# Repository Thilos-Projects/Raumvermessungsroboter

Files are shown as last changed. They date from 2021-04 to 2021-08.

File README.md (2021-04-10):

__Das Projekt findet in Coop mit [Tom Seiffert](https://github.com/Tomsei "Tom Seiffert") statt.__

# Raumvermessungsroboter
## Ziel:

Ein möglichst *einfacher* und *kleiner* Roboter der *autonom* einen flachen Raum von ca. 20x20m abfahren kann und den abgefahrenen Bereich auf einer einfachen Website darstellt.

Hierbei sollen Hindernissen ausgewichen und Kanten vermieden werden.
Nach Möglichkeit sollen nicht statische Hindernisse erkannt und in der Ansicht aktualisiert werden.

Im Weiteren soll der Roboter *keine* äußeren Stationen oder Rechenkapazitäten benötigen. Eine Fernsteuerung für manuelle Operationen soll über ein web interface ermöglicht werden.
Die Entfernungsmessung soll OnBoard über ein *eigenbau* LiDAR System geschehen.
 
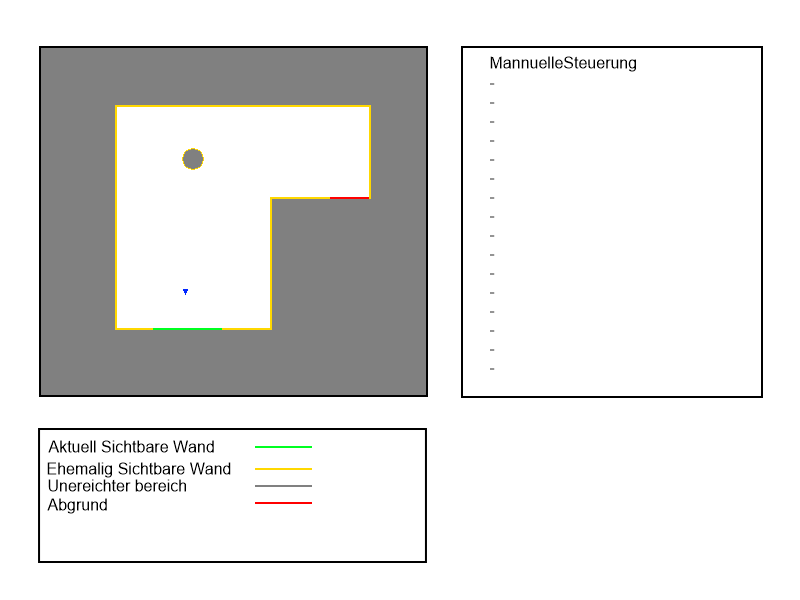
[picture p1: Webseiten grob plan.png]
Webseiten Bild
 
 
## Optionale Erweiterungen:

* Der Roboter soll es ermöglichen ihn an einen punkt in dem gescannten Bereich zu schicken.
* Die daten der Raumvermessung sollen für einen externen Computer über eine schnittstalle in Echtzeit lesbar sein.
* Der Roboter priorisiert in der Raumvermessung Bereiche nah einem gegebenen Punkt über Bereiche, die weiter von diesem entfernt sind.
* Die Webseite zeigt geplante Bewegungen grafisch an.

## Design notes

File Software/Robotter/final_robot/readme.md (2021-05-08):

# Setupinformationen:

* **Entwicklungsboard:** DOIT ESP32 DEVKIT V1

* **Core Debug Level:** None

* **Flash Frequenzy:** 80 Mhz

* **Upload Speed:** 921600

* **Serial Monitor:** 115200

# Code Architektur:

* **Header Programm:** es werden keine .cpp verwendet, sondern nur .h

* **Interrupts:** Management Über Eventssystem

* **Libraries:** Manuell eingebunden im libs Ordner. Gemeinsamer include durch lib_include.h

* **Komponenten:** Komponente wenn möglich als eigenständige Klasse -> Bsp. Motoren, Bodenabstandsmesser...

### Kapselung der Komponenten in Gruppen

1. **Grundkomponenten / Basics:** 
* Motoren 
* Bodenabstandsmesser 
* Ultraschallsensor 
* Laserentfernungsmesser 
* Maussensor 
* Akkustand 
* WiFi 
* LEDs 
* PIN-API
* Lidar-Poty 
* SD Karte 
* Entladeschutz

2. **Komponentenkombiation:** 
* Fahrwerk (1 Seite) -> Motor + Bodenabstandsmesser
* Lidarsystem -> Laserentfernungsmesser + Lidar Poty + Motor
* Abschaltung -> Akuustand + Entladeschutz
* Debughandler -> LEDs + Serielle Schnittstelle

3. **Hauptkomponenten:** 
* Fahrkontrolle --> 2 Fahrwerke + Ultraschallsensor + Maussensor
* Datenkontrolle --> SD Karte
* Lidarkontrolle --> Lidarsystem
* API-Schnittstelle --> WiFi + Pinne 

# Code Style

* Dokumentation auf Deutsch
* Code auf Englisch

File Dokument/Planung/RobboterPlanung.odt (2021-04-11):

Planung

Nötige teile:

- Akku
  - 12V
  - Ladeadapter OnBoard
  - Genug Strom für 20mx20m
- Motoren
  - Schrittmotoren
  - 12V
- Lidar
  - Laser
  - Servos
    - 5V/12V
    - Genauigkeit vor Tempo
- Hinderniserkennung
  - Ultraschallsensor?
- Treppen/Fall Vermeidung
  - Infrarot Reflektion Lichtschranke
- Ketten
  - Glatter wie nicht glatter Untergrund
- LaserMausSensor
  - adns-9800 laser mouse
- Platine
  - Spannungswandler
    - 12V -> 5V
  - Motortreiber/Servotreiber
    - 12V
  - Batterieschutz
    - Lade/Entlade/Kurzschluss/Überspannung
  - Akkuladekreis
  - Ladeanzeige
    - 5 Leds
- Microcontroller
  - Wlan-Host
  - Host für Webseite (Rechenleistung)
- Led
  - Status
    - Ladestand?
  - Designe
  - …
- Knöpfe
  - An/Aus
  - Start/Stopp
  - Ladestand
  - Cash leeren
  - Restart
- Webseite
  - Start/Stopp
- SD-Karte/Speichererweiterung
- Es geht runter Sensor

Motoren: https://www.amazon.de/MVPOWER-Schrittmotor-Stepper-Phase-4-Stepping/dp/B07CZHLKTC/

- 1.5 A | 2.4 V
- 35€ | 5 Motoren | 2 pro Roboter

Motortreiber: https://www.amazon.de/AZDelivery-A4988-Schrittmotor-Treiber-Modul-K%C3%BChlk%C3%B6rper-inklusive/dp/B083V59HTB/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

Datenblatt: https://www.pololu.com/file/0J450/a4988_DMOS_microstepping_driver_with_translator.pdf

- 9€ | 5 Motortreiber | 2 pro Roboter

Servo Motor: Problem keinen richtigen 360° Servo gefunden

- Daher weggeworfen | Eigenbau Poti mit DC Motor

DC Motor: Kreisdrehung https://www.amazon.de/Yosoo-Drehmoment-Getriebemotor-Getriebe-Spielzeug/dp/B01BBSXDJ4/

- 12V | ca.100 ma.
- 6,60€ | 1 Motor | 1 Motor pro Roboter

DC Motortreiber: https://www.amazon.de/Bridge-Driver-Stepper-Controller-Arduino/dp/B077NY9RY6

- 9€ | 2 Treiber | 1 Treiber pro Roboter

Laser Entfernungsmessung: https://www.mouser.de/ProductDetail/Seeed-Studio/101990656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

Datenblatt: https://www.mouser.de/datasheet/2/744/SJ-GU-TF-luna-A01_2bDatasheet-1841241.pdf

- 18€ | ein Abstandsmesser | 1 pro Roboter
- 5V | 3,3V Signal | 70ma

Ultraschallsensoren: https://www.amazon.de/HC-SR04-Ultraschall-Modul-Entfernungssensor-Raspberry-MEGA2560-blau/dp/B081PZF4T3/

- 7€ | 5 Ultraschall | 2 pro Roboter
- 5V

Boden Abstandsmesser | Infrarot Lichtschranke: https://www.amazon.de/MissBirdler-TCRT5000-Lichtschranke-Reflexlichtschranke-Raspberry/dp/B07Q3X9J2V/

- 6 € | 2 im Angebot | 4 pro Roboter -> 12 €

Maus Sensor: https://de.aliexpress.com/item/4000354356293.html?

- 5€ | 1 im kauf | 1 pro Roboter

SD Karten Reader: https://www.amazon.de/AZDelivery-Reader-Speicher-Memory-Arduino/dp/B077MCQS9P/

- 6€ | für 3 | 1 pro Roboter

SD Karte: Laden

Tabelle:

Komponente | Preis | Anzahl | Anzahl im Roboter | Kauf link | Datenblattlink|

Ziele:

- Autonom Fahren
- 20mx20m Fahrbereich
- Webseite Hosting mit raum Darstellungen
- Hindernisse erkennen
- Treppen/Fall Vermeidung
- Hindernisse und fall stellen dynamisch eintragen
- Alles OnBoard
- Fernsteuerung über Web interface
- Entfernung Messung über LiDAR

Optionale Ziele:

- Miniatur tanz Animation
- Manuelle punkt Positionierung
- Webseite mit Rohdaten in Echtzeit
- Scann Logik mit punkt Priorisierung
- Geplante/Alte Bewegungen darstellen (Webseite/Leds)

Meilensteine:

1. Roboter ist fertig
  a. Hardware ist fertig
    i. Spannungsversorgung
      1. Batterie Strom
      2. 5V Leitung
      3. Ladevorgang
      4. Schutzelektronik
    ii. Platine
      5. Alle Teile sind geplant/vorhanden
        a. Einzelkomponenten funktionieren
      6. Platine ist geplant und getestet
    iii. LiDAR
      7. Sensor vorhanden/funktionsfähig
      8. Servos funktionsfähig
      9. 3D Modell für Halterung fertig/gedruckt und passend
    iv. Eventuelle 3D Komponenten
      10. Komponenten/ Halterungen modelliert
      11. Komponenten/ Halterungen gedruckt und passend
    v. Roboter Zusammenbau
  b. Software ist fertig
    vi. Komponenten Test
      12. Platine
        b. Einzel Komponenten Tests
        c. Gruppen Komponenten Tests
        d. Einfache Fahrroutiene
      13. LiDAR
        e. Laser liefert Abstandes werte
        f. Servo dreht richtig
        g. Daten sind ab speicherbar
      14. Webseite
        h. Daten in Tabelle
        i. Daten darstellen (Skizze)
        j. Manuelle Steuerung
          i. Joystick
          ii. Fahr zu punkt
        k. Schön machen
    vii. Gruppen Test
      15. Einfache Fahrroutiene plus scannen und darstellen
      16. Punkt anfahren
      17. Ruhe Task (Leds?)

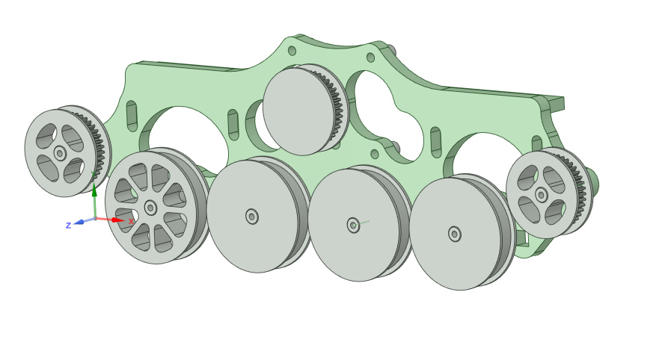
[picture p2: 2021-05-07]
Dokument/Bilder/Fahrwerk/Fahrwerk_Planung_1.PNG

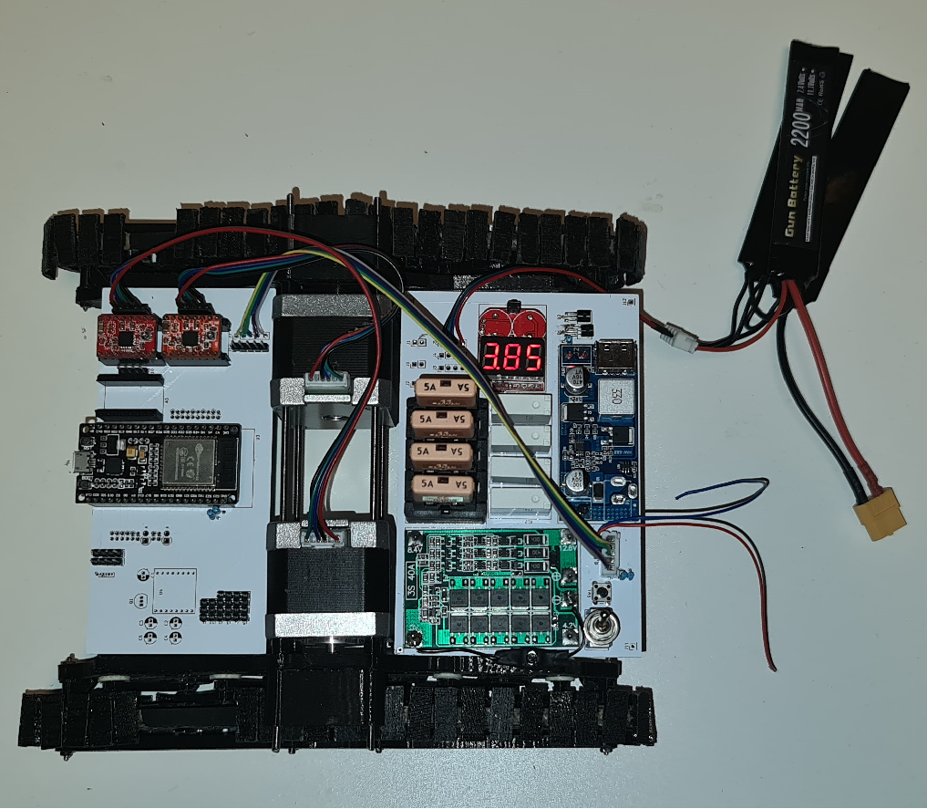
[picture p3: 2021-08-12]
Dokument/Bilder/Schritt4.png

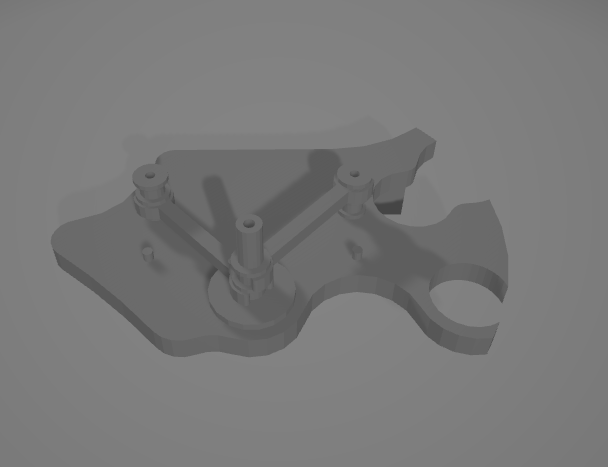
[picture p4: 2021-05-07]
Dokument/Bilder/Fahrwerk/Federung.PNG

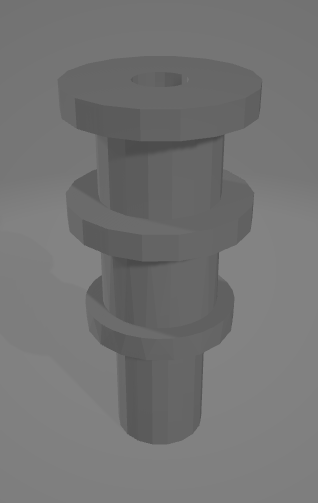
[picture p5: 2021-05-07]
Dokument/Bilder/Fahrwerk/Federung_Achse.PNG

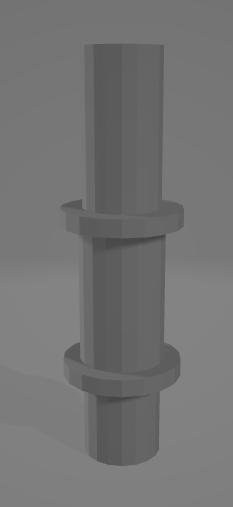
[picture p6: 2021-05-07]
Dokument/Bilder/Fahrwerk/ZahnRad_Achse.PNG

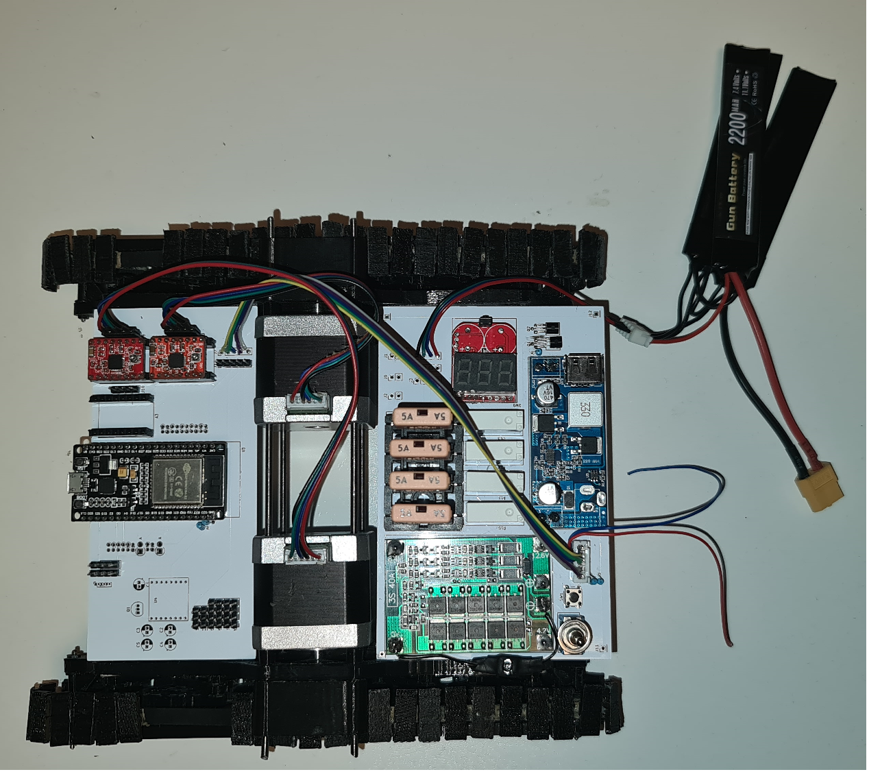
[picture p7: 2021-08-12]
Dokument/Bilder/Schritt1.png

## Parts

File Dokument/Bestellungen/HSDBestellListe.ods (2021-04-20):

Nr | Anzahl | Name | Liferant | Link | Artikklenummer/EAN | Einzelpreis | Gesamtpreis
1 | 4 | Motor | Reichelt | https://www.reichelt.de/schrittmotor-hoch-drehmoment-hybrid-2-phasen-nema17-01-p219027.html | 9900002190277 | 25,8 | 103,2
2 | 2 | Motor Treiber | Conrad | https://www.conrad.de/de/p/5x-a4988-stepstick-kompatibel-schrittmotortreiber-fuer-3d-drucker-802287483.html | 4060137004896 | 12,58 | 25,16
3 | 3 | Laser Entfernungsmesser | Mauser | https://www.mouser.de/ProductDetail/Seeed-Studio/101990656?qs=vmHwEFxEFR%2FGuLjB%252BDw9Gg==&mgh=1&vip=1 | 101990656 | 20,84 | 62,52
4 | 3 | Sicherungshalter | Conrad | https://www.conrad.de/de/p/mpfa05-11-l-fuse-holder-5xato-pcb-800204758.html | 2032-MPFA05-11-L | 3,18 | 9,54
5 | 1 | Akku | Conrad | https://www.conrad.de/de/p/gens-ace-modellbau-akkupack-lipo-11-1-v-5000-mah-zellen-zahl-3-50-c-ec5-2145188.html | 6928493323106 | 34,45 | 34,45
6 | 12 | Relays | Reichelt | https://www.reichelt.de/miniatur-leistungsrelais-hf-12v-1-schliesser-5a-hf-46f-12v-p112505.html | 9900001125058 | 0,73 | 8,76
7 | 3 | Schalter | Reichelt | https://www.reichelt.de/miniatur-kippschalter-ein-aus-ein-3-a-250-v-goobay-10022-p285989.html | 4040849100222 | 0,56 | 1,68
 |  |  |  |  |  | Summe | 245,31

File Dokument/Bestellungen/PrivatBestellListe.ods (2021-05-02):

Nr | Anzahl | Name | Liferant | Link | Einzelpreis | Gesamtpreis
1 | 6 | Ultraschall sensor | Ali | https://de.aliexpress.com/item/1005001834937665.html | 0,9 | 5,4
2 | 12 | BodenabstandsMesser | Ali | https://de.aliexpress.com/item/4000077217976.html | 0,54 | 6,48
3 | 3 | Maussensor | Ali | https://de.aliexpress.com/item/4000354356293.html | 4,63 | 13,89
4 | 3 | SDCard Reader | Ali | https://de.aliexpress.com/item/32572793362.html | 0,38 | 1,14
5 | 3 | Spannungswandler(12_5) | Ali | https://de.aliexpress.com/item/4000063772472.html | 1,28 | 3,84
6 | 3 | Sicherung | Amazon | https://www.amazon.de/MagiDeal-R%C3%BCckstellbare-Sicherung-manuelle-Leistungsschalter/dp/B0742DRRZC (https://www.amazon.de/MagiDeal-Rückstellbare-Sicherung-manuelle-Leistungsschalter/dp/B0742DRRZC) | 7,99 | 23,97
7 | 3 | Schutzkreis | Ali | https://de.aliexpress.com/item/4000434494123.html | 2,44 | 7,32
8 | 3 | Entladeschutz | Ali | https://de.aliexpress.com/item/4000874198281.html | 0,74 | 2,22
9 | 2 | Akku | Ali | https://de.aliexpress.com/item/1005001722330602.html | 32,95 | 65,9
10 | 1 | Motoren | Amazon | https://www.amazon.de/MVPOWER-Schrittmotor-Stepper-Phase-4-Stepping/dp/B07CZHLKTC | 36,99 | 36,99
 |  |  |  |  | Summe | 167,15

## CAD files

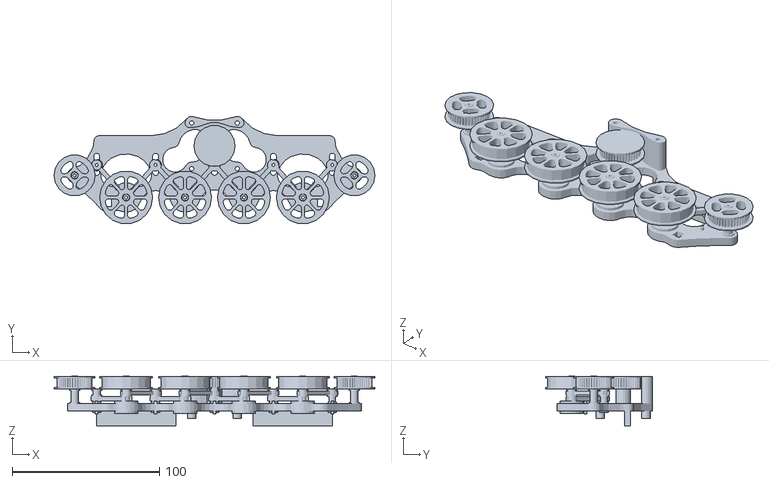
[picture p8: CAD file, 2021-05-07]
3D_Komponenten/Fahrwerk/Fahrwerk.stl
218.0 x 72.7 x 33.7

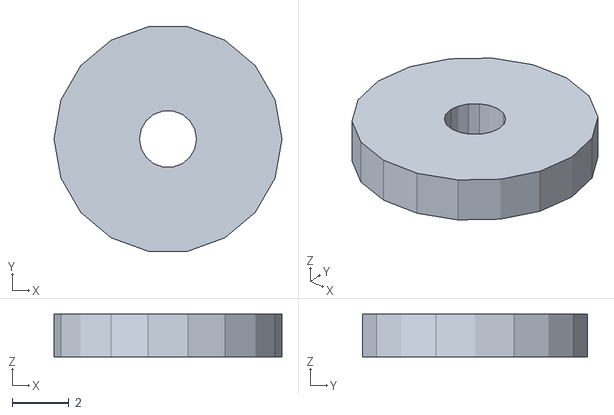
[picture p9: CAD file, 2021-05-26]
3D_Komponenten/Fahrwerk/STLs/Fahrwerk_Unterlegscheibe.stl
8.00 x 7.88 x 1.50

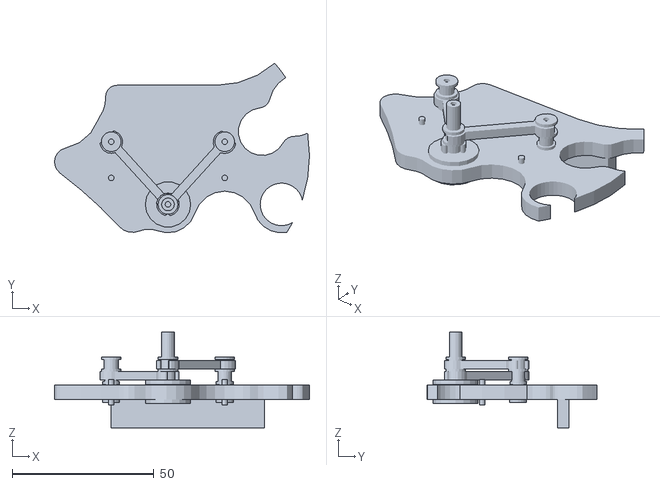
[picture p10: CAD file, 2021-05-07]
Dokument/Bilder/Fahrwerk/Federung.stl
89.9 x 59.7 x 33.7

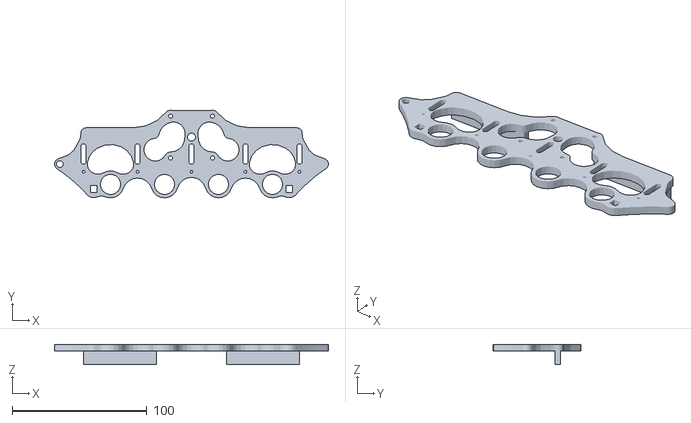
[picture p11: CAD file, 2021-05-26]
3D_Komponenten/Fahrwerk/STLs/Fahrwerk_grundplatte.stl
203.0 x 65.0 x 15.0

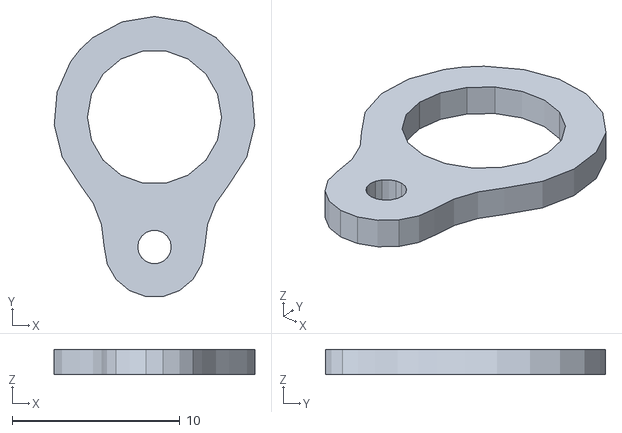
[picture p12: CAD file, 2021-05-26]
3D_Komponenten/Fahrwerk/STLs/Fahrwerk_Gumi.stl
12.0 x 16.7 x 1.50

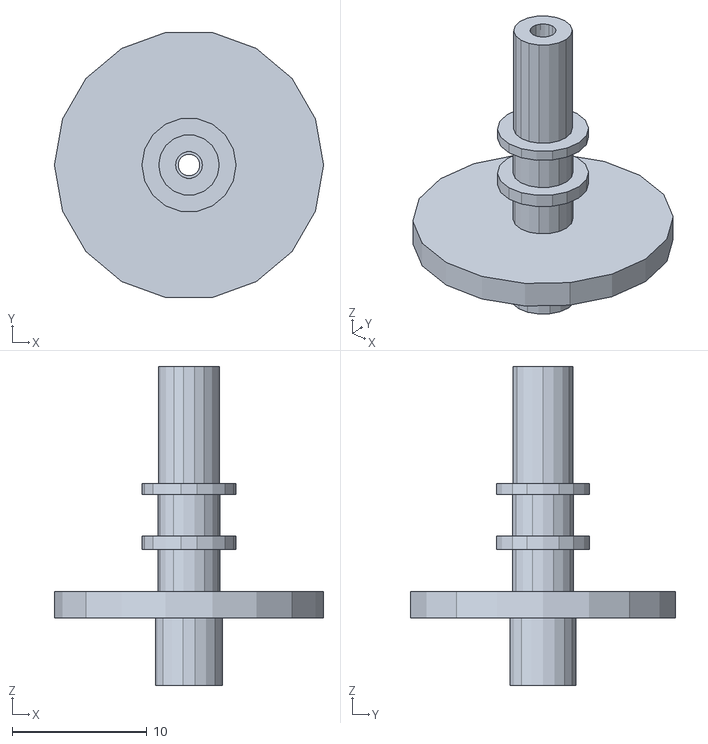
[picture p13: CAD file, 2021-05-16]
3D_Komponenten/Fahrwerk/STLs/Fahrwerk_Rad_Achse_0.stl
20.0 x 19.7 x 23.7

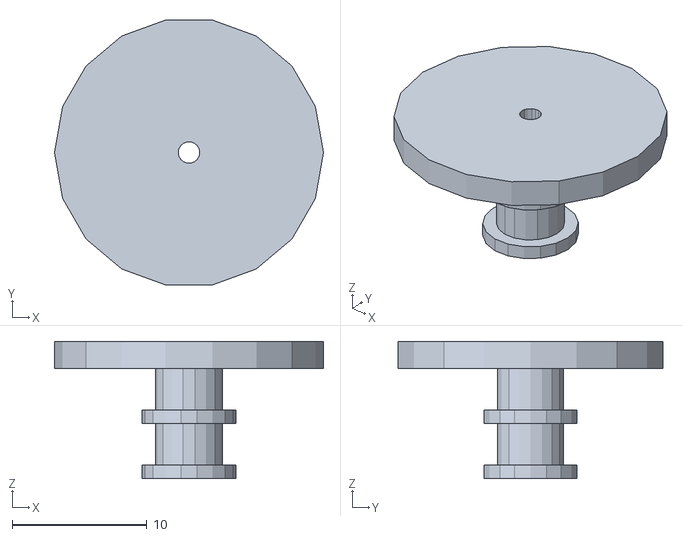
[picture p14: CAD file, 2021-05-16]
3D_Komponenten/Fahrwerk/STLs/Fahrwerk_Rad_Achse_1.stl
20.0 x 19.7 x 10.2

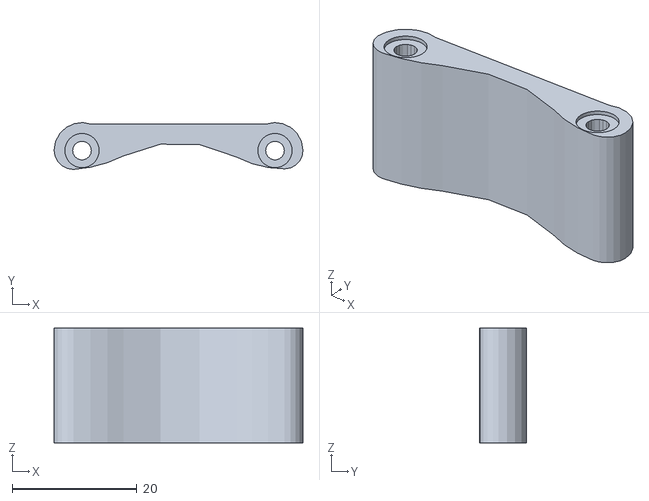
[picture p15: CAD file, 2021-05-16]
3D_Komponenten/Fahrwerk/STLs/Fahrwerk_KettenHalterung.stl
40.0 x 7.53 x 18.4

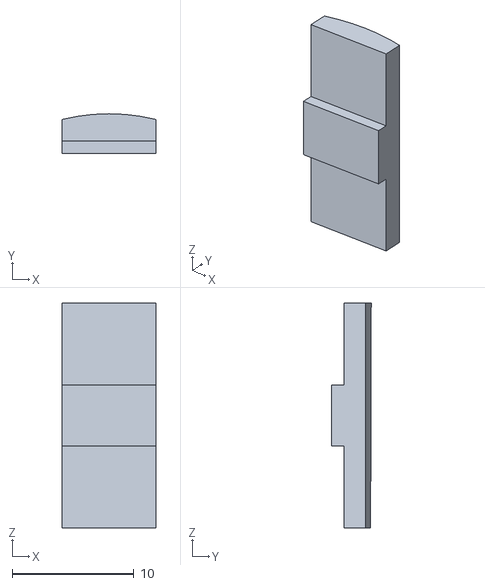
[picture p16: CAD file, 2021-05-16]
3D_Komponenten/Fahrwerk/STLs/Fahrwerk_KettenGlied.stl
7.75 x 3.25 x 18.5

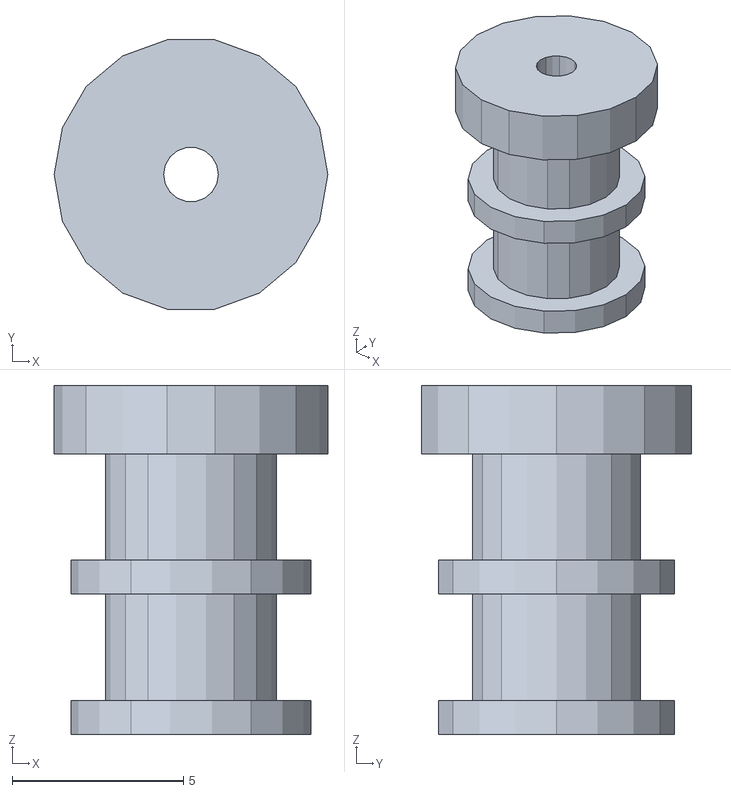
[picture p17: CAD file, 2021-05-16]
3D_Komponenten/Fahrwerk/STLs/Fahrwerk_Federungs_Achse_1.stl
8.00 x 7.88 x 10.2

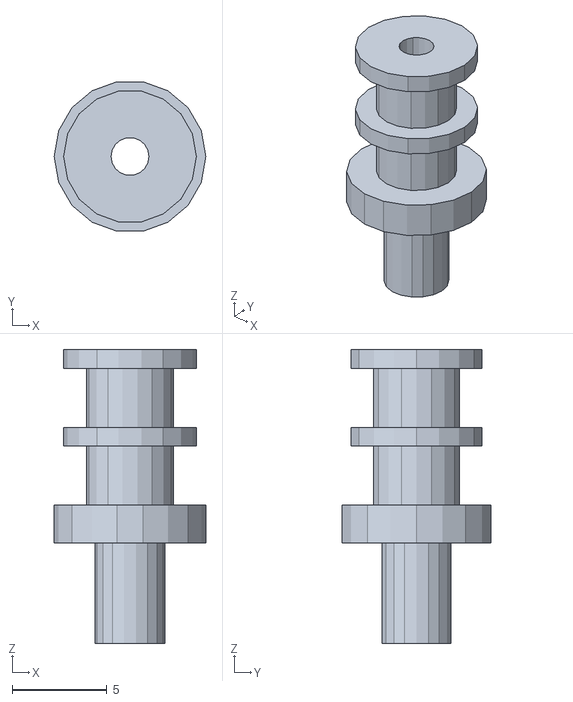
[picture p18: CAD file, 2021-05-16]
3D_Komponenten/Fahrwerk/STLs/Fahrwerk_Federungs_Achse_0.stl
8.00 x 7.88 x 15.5

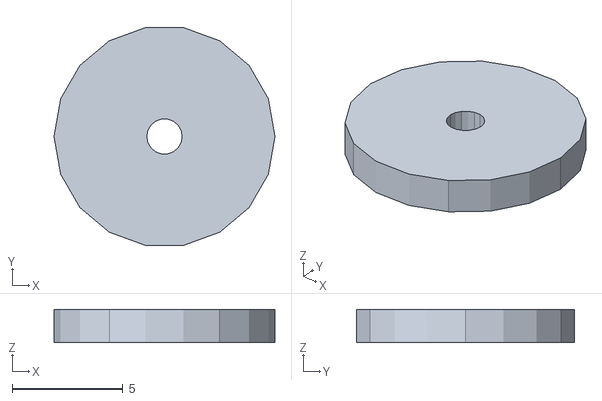
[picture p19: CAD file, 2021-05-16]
3D_Komponenten/Fahrwerk/STLs/Fahrwerk_Unterlegscheibe_mittel.stl
10.0 x 9.85 x 1.50

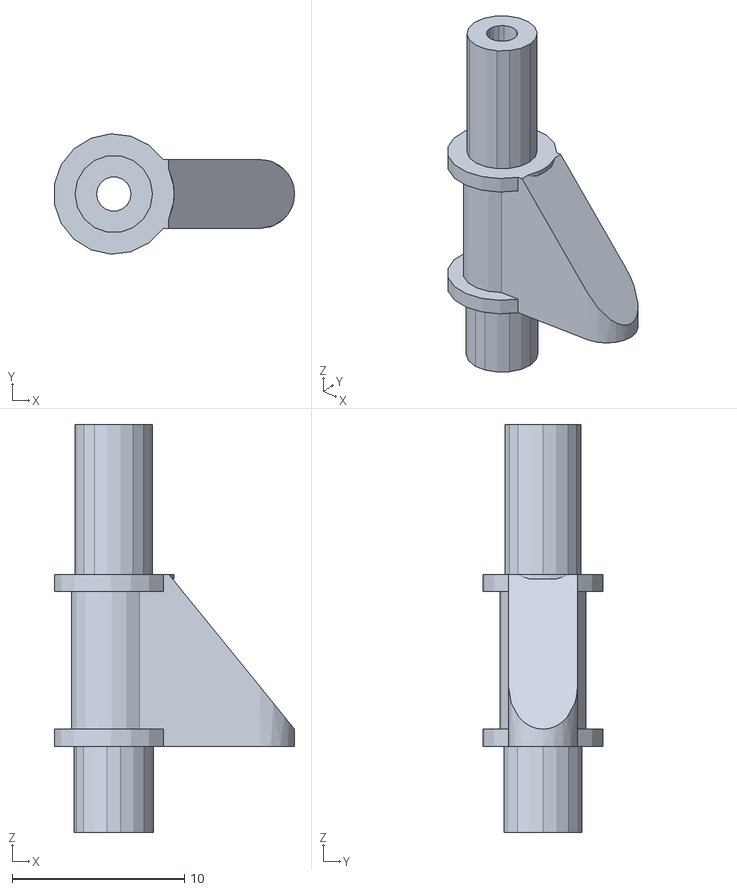
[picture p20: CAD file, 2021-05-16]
3D_Komponenten/Fahrwerk/STLs/Fahrwerk_Zahn_Rad_Achse.stl
14.0 x 6.99 x 23.7

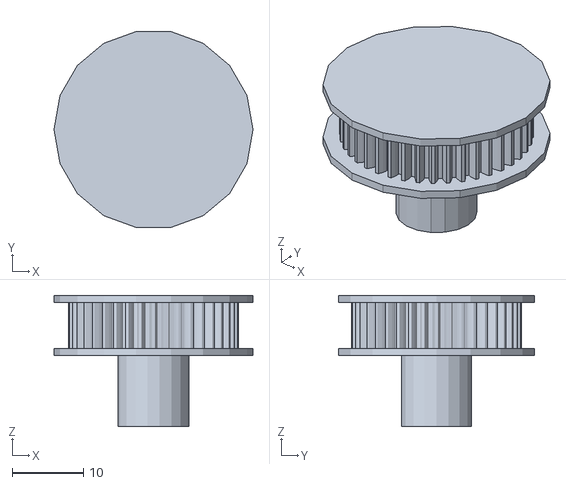
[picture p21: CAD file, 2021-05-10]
3D_Komponenten/Fahrwerk/STLs/Fahrwerk_Motor_Rad.stl
28.0 x 27.6 x 18.4

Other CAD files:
3D_Komponenten/Fahrwerk/STLs/Fahrwerk_Unterlegscheibe_klein.stl
3D_Komponenten/Fahrwerk/STLs/Fahrwerk_Federungs_Anker.stl
3D_Komponenten/Fahrwerk/STLs/Fahrwerk_Federungs_abstandshalter.stl
3D_Komponenten/Fahrwerk/STLs/Fahrwerk_Rad.stl
3D_Komponenten/Fahrwerk/STLs/Fahrwerk_Federungs_Gummi_Pine.stl
3D_Komponenten/Fahrwerk/STLs/Fahrwerk_Motor_Abstandshalter.stl
3D_Komponenten/Fahrwerk/STLs/Fahrwerk_Zahn_Rad.stl

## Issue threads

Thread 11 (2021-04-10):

Platine ist getestet

Thilos-Projects, 2021-04-10:
alle Komponenten auf der Platine sind richtig verbunden und  werden entsprechend versorgt
Alle elektrischen zusammenhänge auf der Platine sind richtig und getestet

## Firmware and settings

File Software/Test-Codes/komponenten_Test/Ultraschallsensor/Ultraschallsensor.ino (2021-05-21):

#include <Wire.h>

const int triggerPin = 2; 
const int echoPin = 15;


void setup() {
  // put your setup code here, to run once:
  Serial.begin(115200);

  pinMode(triggerPin, OUTPUT);
  pinMode(LED_BUILTIN, OUTPUT);
  pinMode(echoPin, INPUT);
  digitalWrite(triggerPin, HIGH);
  
  Serial.println("Setup Done");
}

void loop() {

  float distance = get_distance();
  // put your main code here, to run repeatedly:
  Serial.print("[Ultraschall]:: distance: ");
  Serial.println(distance);
 
  delay(100);
}


/*
Methode bietet die Distanz in verwendung von pulseIn
Signal wird ausgesendet und die Zeit gemessen, die notwneidg ist, bis Signal zurück kommt
*/
float get_distance() {

  float duration=0;
  float distance=0;

  digitalWrite(triggerPin, LOW);
  delayMicroseconds(2);
  noInterrupts();
  digitalWrite(triggerPin, HIGH);
  delayMicroseconds(10);
  digitalWrite(triggerPin, LOW);
  duration = pulseIn(echoPin, HIGH); // Erfassung - Dauer in Mikrosekunden
  interrupts();

  distance = (duration / 2) / 29.1; // Distanz in CM
  return(distance);
}

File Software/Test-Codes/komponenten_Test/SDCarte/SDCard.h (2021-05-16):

#include "libs/lib_include.h"

class SDCardUtill{
public:

  //
  //Forbidden pins For SPI:
  //  1,3,6,7,8
  //
  typedef struct{
    public:
      byte MOSI = 0;
      byte MISO = 4;
      byte CS = 15;
      byte SCK = 2;
      bool SPIH = true;
  } pinConfig;

  bool begin(pinConfig* conf){

    pinConf = *conf;

    if(pinConf.SPIH)
      this->spi = new SPIClass(HSPI);
    else
      this->spi = new SPIClass(VSPI);

    spi->begin(pinConf.SCK, pinConf.MISO, pinConf.MOSI, pinConf.CS);
    return mySD.begin(pinConf.CS, *spi) && SD.cardType() != CARD_NONE;
  }
  
  uint64_t getCardSize(){
    return mySD.cardSize() / (1024 * 1024);
  }

private:
  fs::SDFS mySD = fs::SDFS(std::make_shared<VFSImpl>(VFSImpl()));
  SPIClass *spi;
  pinConfig pinConf;

  bool createDir(const char * path){
    return mySD.mkdir(path);
  }

  bool exists(const char * path){
    return mySD.exists(path);
  }

  File getFile(const char * path, bool canCreate, bool isAppend){
    if(isAppend)
      return mySD.open(path, FILE_APPEND);
    if(canCreate)
      return mySD.open(path, FILE_WRITE);
    return mySD.open(path, FILE_READ);
  }

  bool removeFile(const char * path){
    return mySD.remove(path);
  }
};

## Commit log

2021-04-11 Abspeichern der kommunikation
2021-05-02 Fahrwerk planung
    [Fahrwerk_grundplatte.stl, Fahrwerk_grundplatte_Pinne.stl, Fahrwerk_grundplatte_zahnRad_Klein.stl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]
2021-05-07 FahrWerk 3D planung abgeschlossen
    [Fahrwerk_grundplatte.stl, Fahrwerk_grundplatte_Pinne.stl, Fahrwerk_grundplatte_zahnRad_Klein.stl]
2021-05-07 Documenten Strukturierung + STLs
    [Fahrwerk_Federungs_Achse.stl, Fahrwerk_Federungs_Anker.stl, Fahrwerk_Federungs_Gummi_Pine.stl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]
2021-05-07 STD Fahrwerk
    [Fahrwerk.stl]
2021-05-07 FehlerKorrektur Achsen durchmesser
    [Fahrwerk_Federungs_Achse.stl, Fahrwerk_Rad_Achse.stl]
2021-05-10 Größenanpassung
    [Fahrwerk_KettenHalterung.stl, Fahrwerk_Motor_Rad.stl]
2021-05-16 3D Komponenten Anpassung
    [Fahrwerk_Federungs_Achse.stl, Fahrwerk_Federungs_Achse_0.stl, Fahrwerk_Federungs_Achse_1.stl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]
2021-05-26 Grundplatten anpassung
    [Fahrwerk_Gumi.stl, Fahrwerk_Unterlegscheibe.stl, Fahrwerk_grundplatte.stl]
